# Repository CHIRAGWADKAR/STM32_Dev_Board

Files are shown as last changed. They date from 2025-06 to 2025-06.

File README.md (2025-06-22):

# STM32 PCB Design Project

## STM32F103C8T6 Dev Board (Custom PCB)

This repository contains the complete KiCad project files for a custom development board based on the **STM32F103C8T6** microcontroller, 
commonly used in embedded systems and ARM Cortex-M3 learning platforms.

Designed by: **Chirag Wadkar**  
Toolchain: **KiCad 5.1.15**

---

## 🔧 Features & Specifications

- **Microcontroller**: STM32F103C8T6 (ARM Cortex-M3, 72 MHz, 64 KB Flash, 20 KB RAM)
- **Voltage Regulation**: AMS1117-3.3 LDO with LED power indicator
- **Power Supply**: USB Micro-B (VBus) → 3.3V regulated
- **External Oscillator**:
  - 16 MHz crystal connected to PD0 (HSE_IN) & PD1 (HSE_OUT)
- **USB Interface**:
  - USB Micro-B connected to PA11 (D-) and PA12 (D+)
  - 1.5kΩ pull-up resistor on D+
- **Communication**:
  - UART: PB6 (TX), PB7 (RX)
  - I2C: PB10 (SCL), PB11 (SDA)

---

## 📷 Screenshots

### 🔌 Schematic View
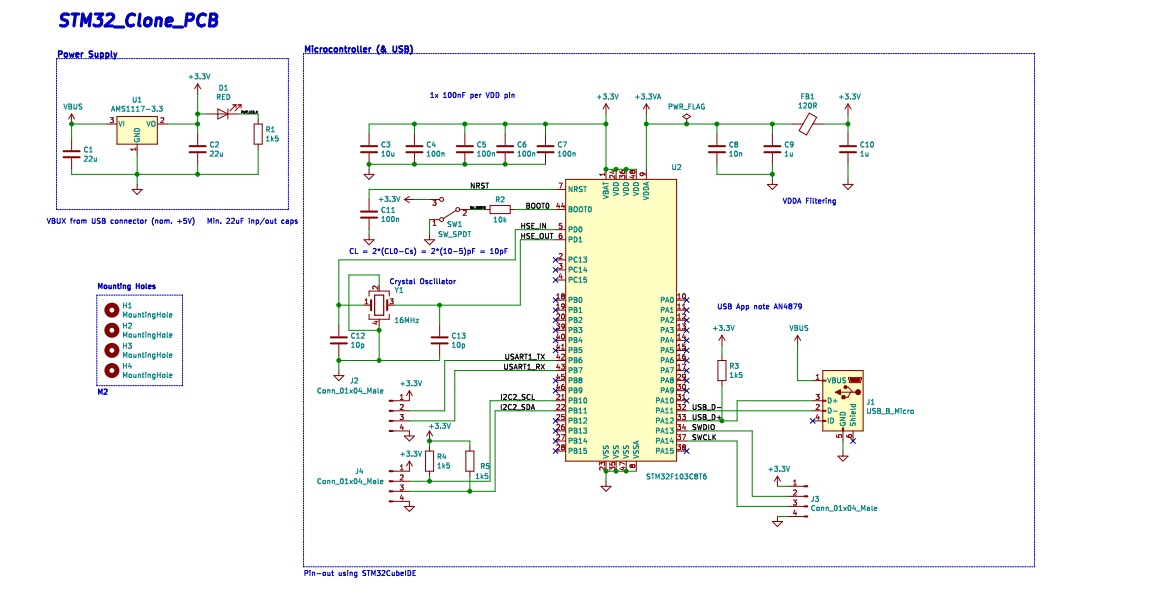
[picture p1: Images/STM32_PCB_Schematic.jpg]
Schematic


### 💻 PCB Layout
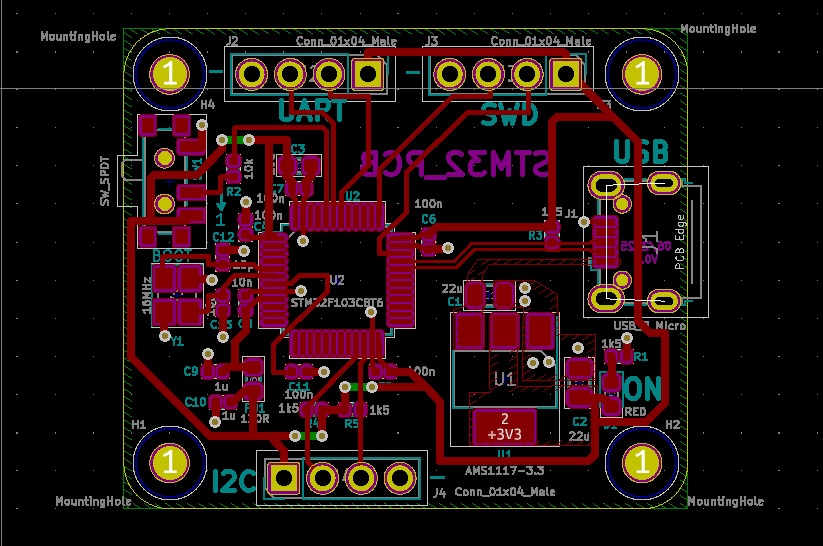
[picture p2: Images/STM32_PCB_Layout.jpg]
PCB Layout


### 🧱 3D Render
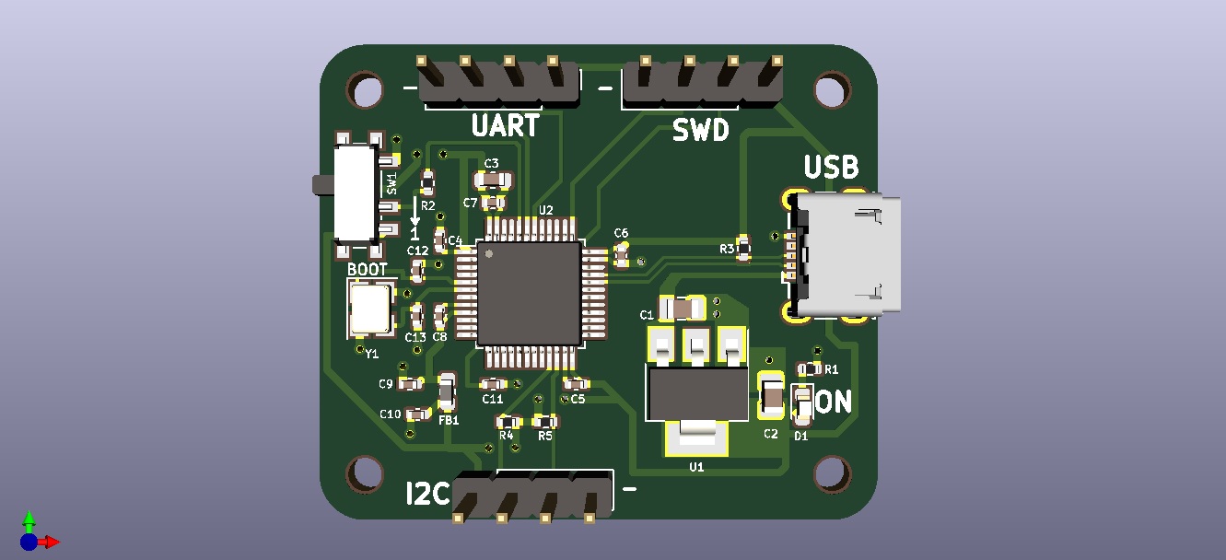
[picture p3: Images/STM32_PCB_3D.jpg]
3D PCB


---

## 🔌 Powering & Programming

- **Power Input**: USB Micro-B (VBus 5V → Regulated to 3.3V)
- **Programming Methods**:
  - Via USB (DFU mode)
  - External SWD programmer via SWDIO/SWCLK pins.

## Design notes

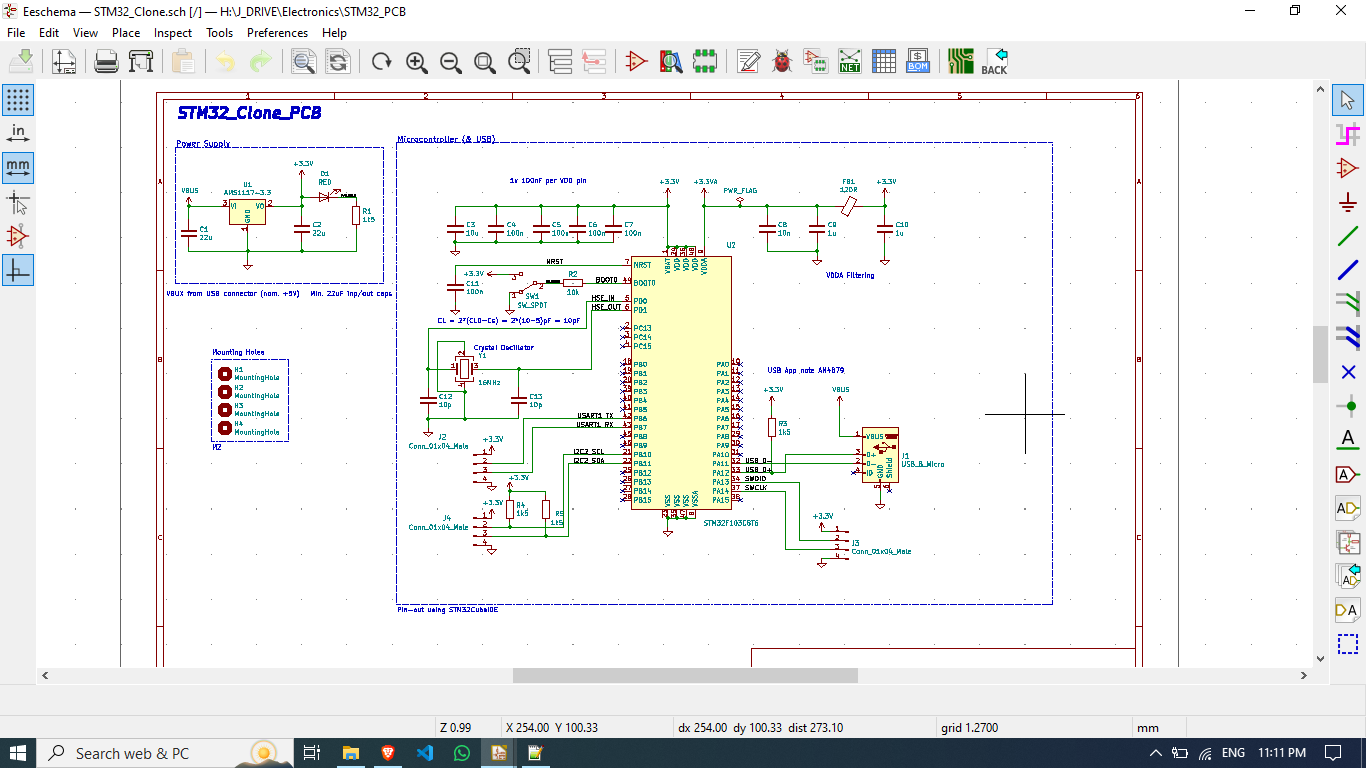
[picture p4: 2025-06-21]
Images/STM32_PCB_Schematic_KiCad.png

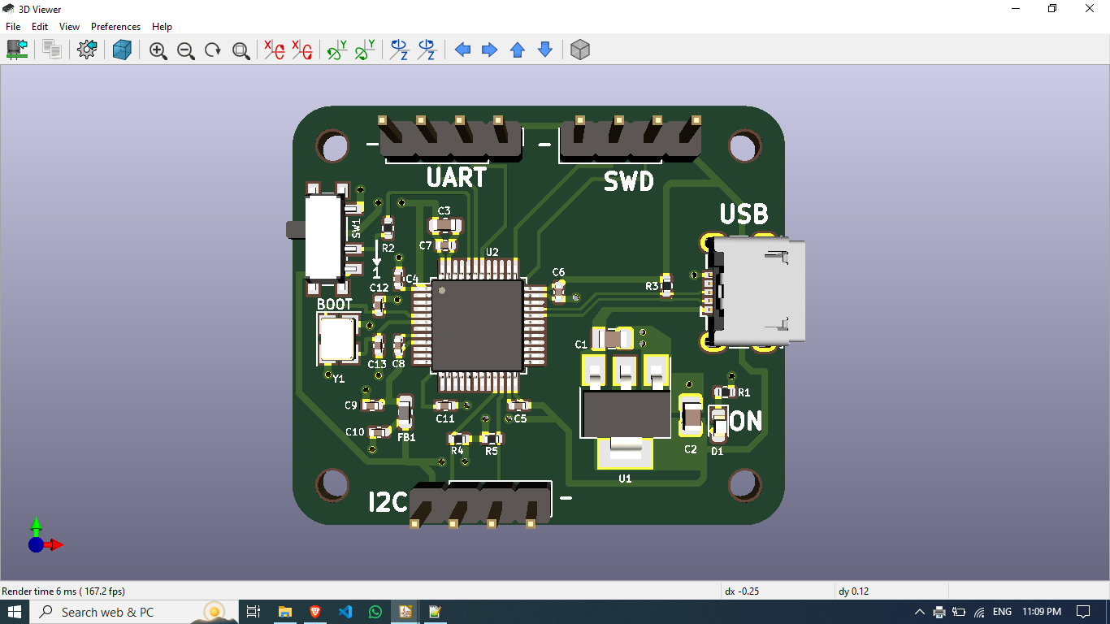
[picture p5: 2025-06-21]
Images/STM32_PCB_3D_KiCad.png

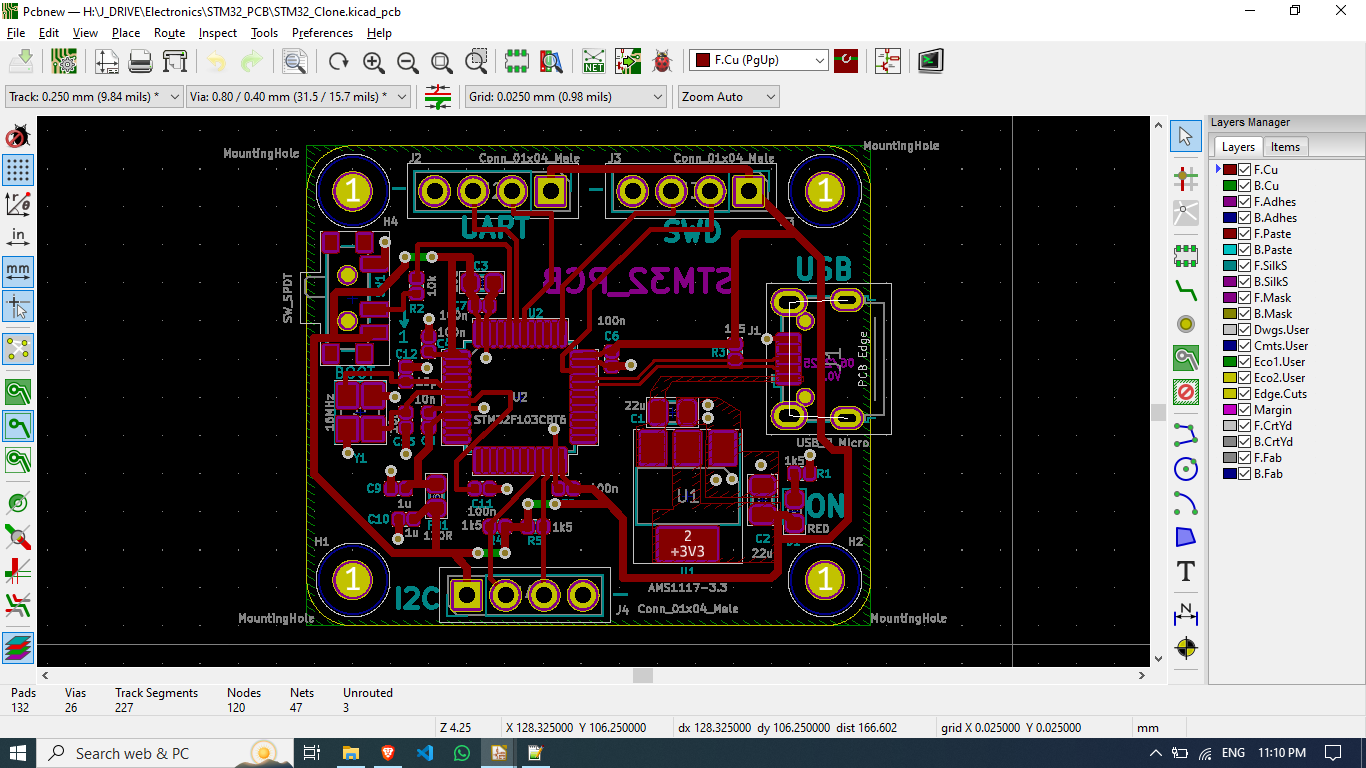
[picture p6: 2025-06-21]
Images/STM32_PCB_Layout_KiCad.png

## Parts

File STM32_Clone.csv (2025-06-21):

Source: | H:\J_DRIVE\Electronics\STM32_Clone\STM32_Clone.sch
Date: | 17-Jun-25 8:03:20 PM
Tool: | Eeschema (5.1.10)-1
Generator: | C:\Program Files\KiCad\bin\scripting\plugins/bom_csv_grouped_by_value_with_fp.py
Component Count: | 32
Ref | Qnty | Value | Cmp name | Footprint | Description | Vendor
C1, C2, | 2 | 22u | C | Capacitor_SMD:C_0805_2012Metric | Unpolarized capacitor
C3, | 1 | 10u | C | Capacitor_SMD:C_0603_1608Metric | Unpolarized capacitor
C4, C5, C6, C7, C11, | 5 | 100n | C | Capacitor_SMD:C_0402_1005Metric | Unpolarized capacitor
C8, | 1 | 10n | C | Capacitor_SMD:C_0402_1005Metric | Unpolarized capacitor
C9, C10, | 2 | 1u | C | Capacitor_SMD:C_0402_1005Metric | Unpolarized capacitor
C12, C13, | 2 | 10p | C | Capacitor_SMD:C_0402_1005Metric | Unpolarized capacitor
D1, | 1 | RED | LED | LED_SMD:LED_0603_1608Metric | Light emitting diode
FB1, | 1 | 120R | Ferrite_Bead | Inductor_SMD:L_0603_1608Metric | Ferrite bead
H1, H2, H3, H4, | 4 | MountingHole | MountingHole | MountingHole:MountingHole_2.2mm_M2 | Mounting Hole without connection
J1, | 1 | USB_B_Micro | USB_B_Micro | Connector_USB:USB_Micro-B_Wuerth_629105150521 | USB Micro Type B connector
J2, J3, J4, | 3 | Conn_01x04_Male | Conn_01x04_Male | Connector_PinHeader_2.54mm:PinHeader_1x04_P2.54mm_Vertical | Generic connector, single row, 01x04, script generated (kicad-library-utils/schlib/autogen/connector/)
R1, R3, R4, R5, | 4 | 1k5 | R | Resistor_SMD:R_0402_1005Metric | Resistor
R2, | 1 | 10k | R | Resistor_SMD:R_0402_1005Metric | Resistor
SW1, | 1 | SW_SPDT | SW_SPDT | Button_Switch_SMD:SW_SPDT_PCM12 | Switch, single pole double throw
U1, | 1 | AMS1117-3.3 | AMS1117-3.3 | Package_TO_SOT_SMD:SOT-223-3_TabPin2 | 1A Low Dropout regulator, positive, 3.3V fixed output, SOT-223
U2, | 1 | STM32F103C8T6 | STM32F103C8Tx | Package_QFP:LQFP-48_7x7mm_P0.5mm | ARM Cortex-M3 MCU, 64KB flash, 20KB RAM, 72MHz, 2-3.6V, 37 GPIO, LQFP-48
Y1, | 1 | 16MHz | Crystal_GND24 | Crystal:Crystal_SMD_3225-4Pin_3.2x2.5mm | Four pin crystal, GND on pins 2 and 4

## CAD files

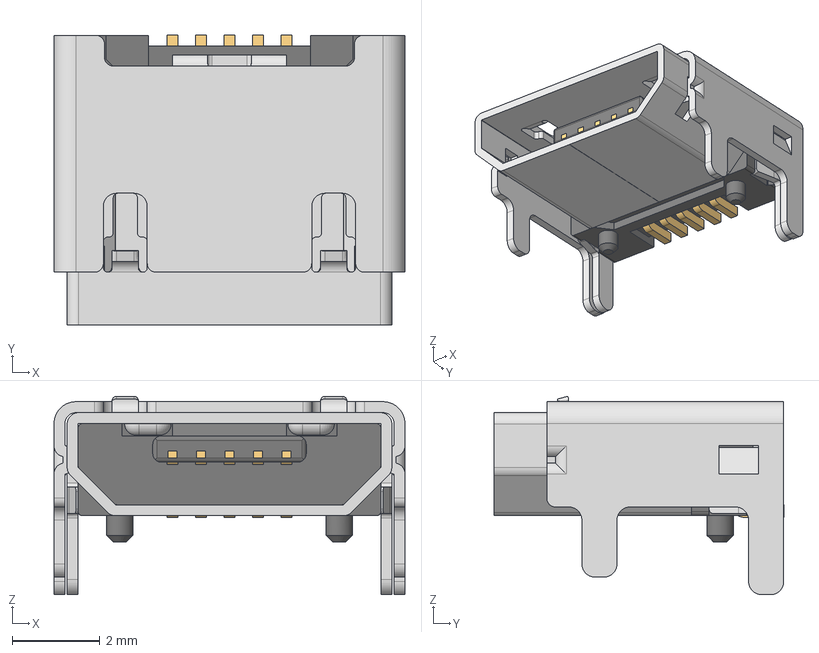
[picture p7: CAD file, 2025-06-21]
629105150521 (rev1).stp
8.00 x 6.60 x 4.52 mm
629105150521_Housing
629105150521_Pin1 x 4
629105150521_Pin2
629105150521_Shielding2
629105150521_Shielding

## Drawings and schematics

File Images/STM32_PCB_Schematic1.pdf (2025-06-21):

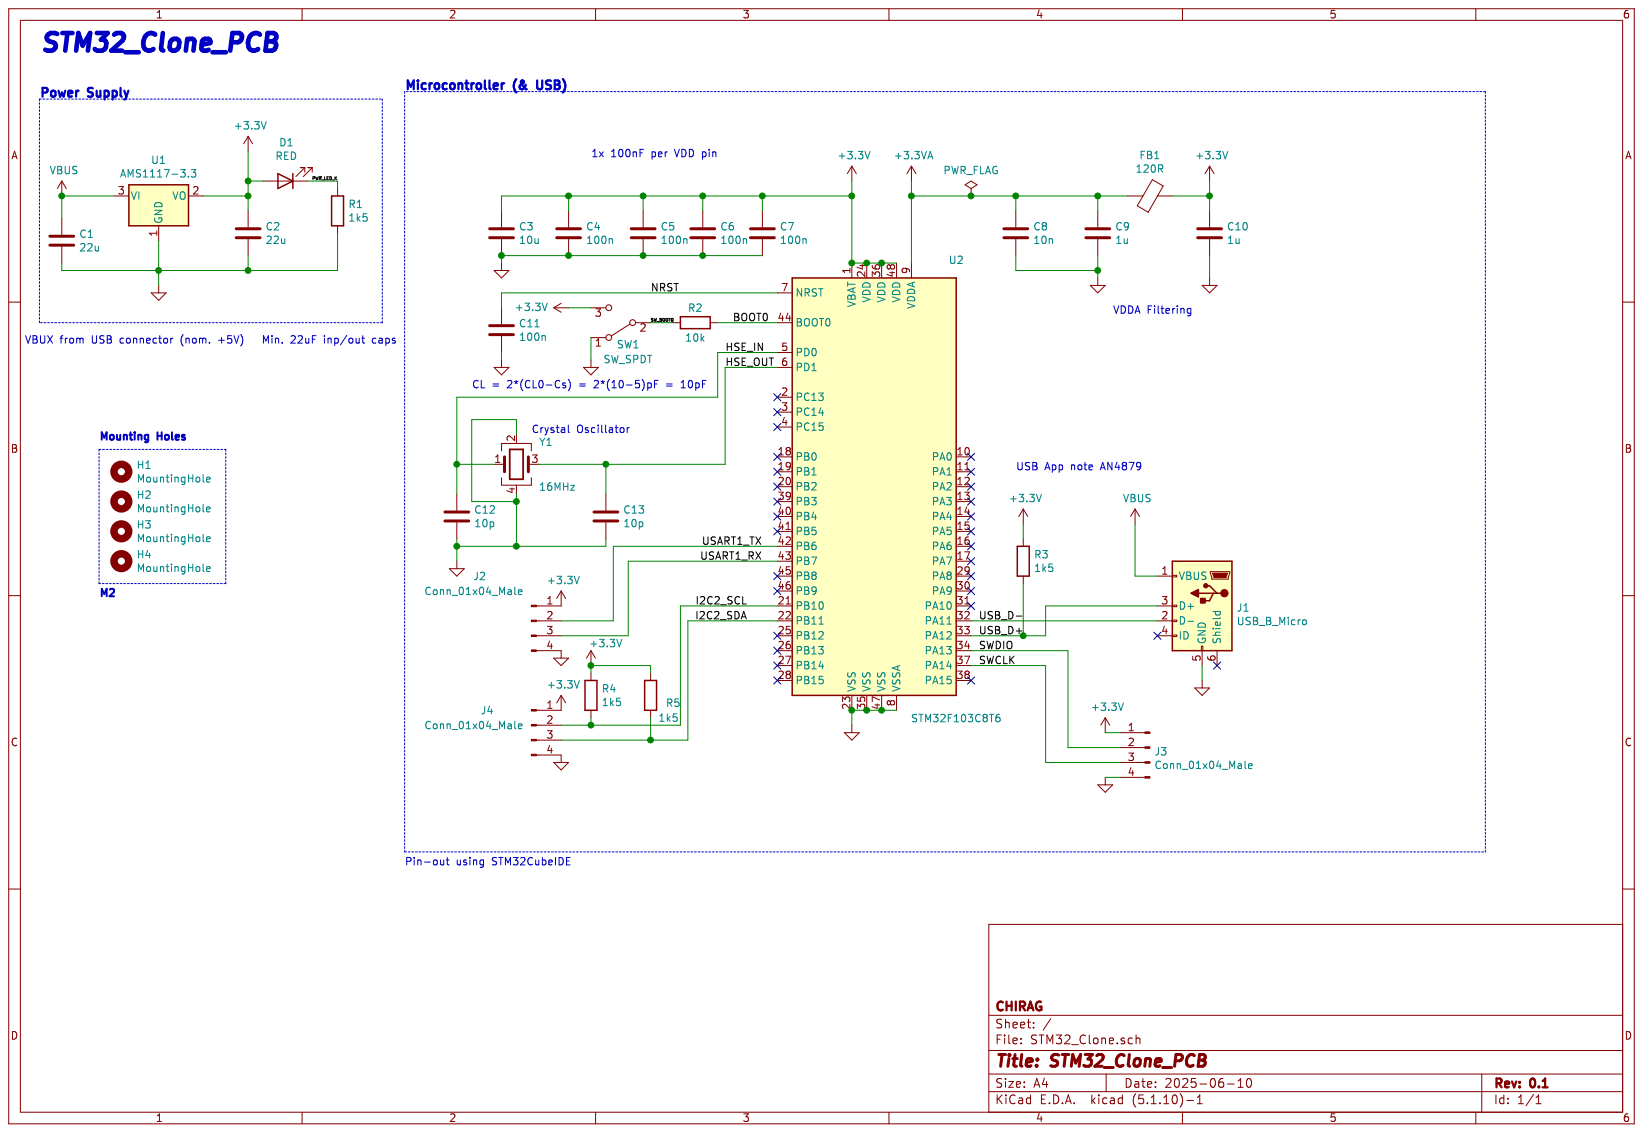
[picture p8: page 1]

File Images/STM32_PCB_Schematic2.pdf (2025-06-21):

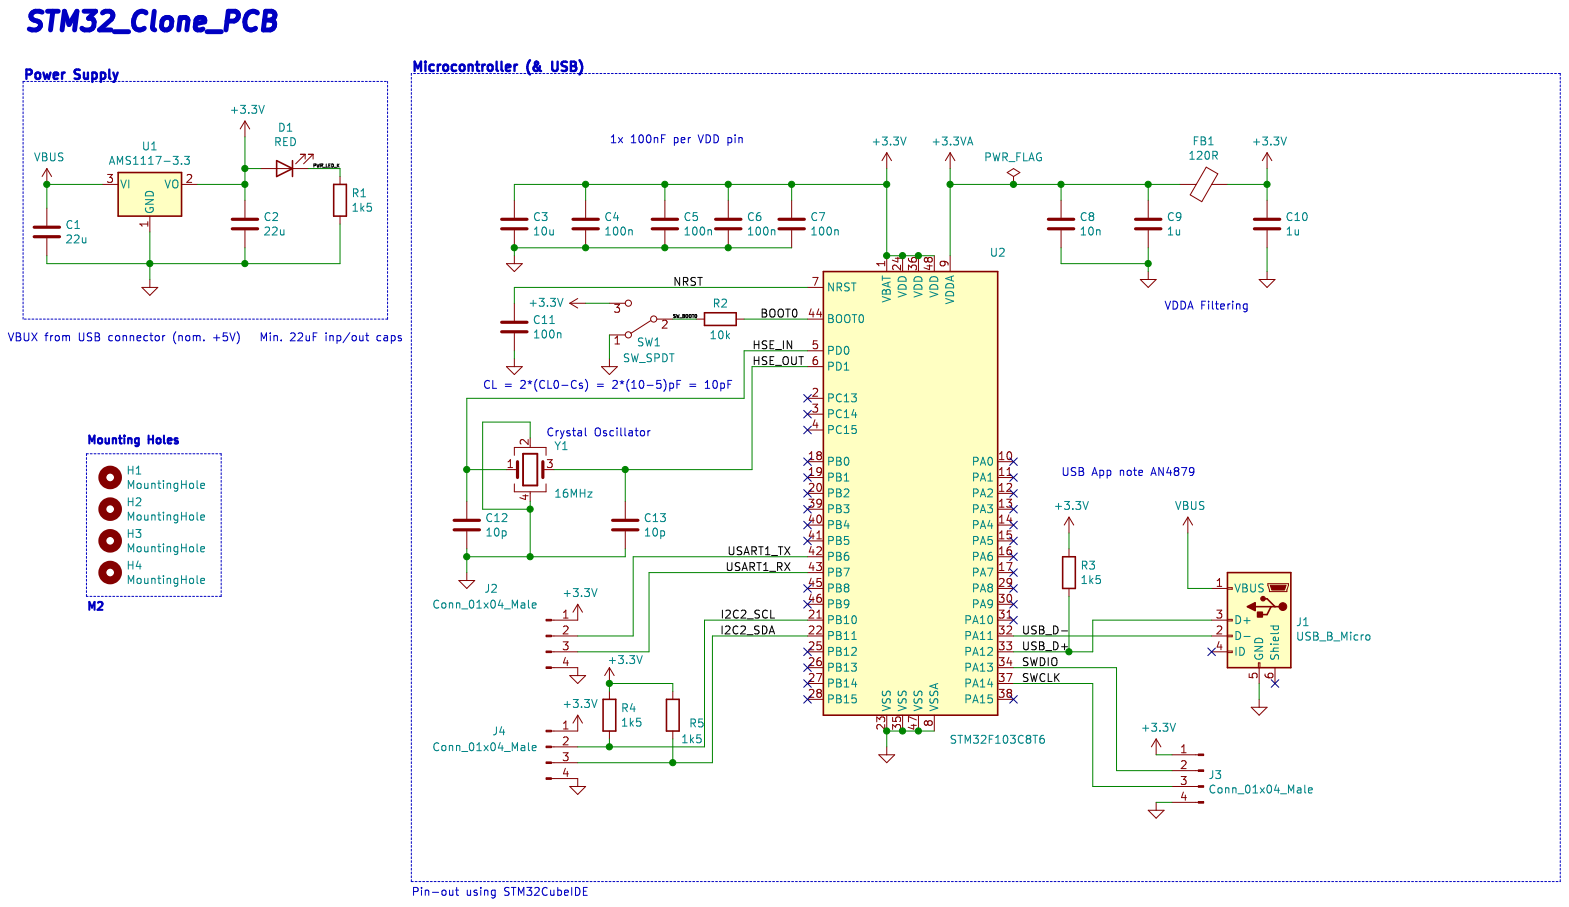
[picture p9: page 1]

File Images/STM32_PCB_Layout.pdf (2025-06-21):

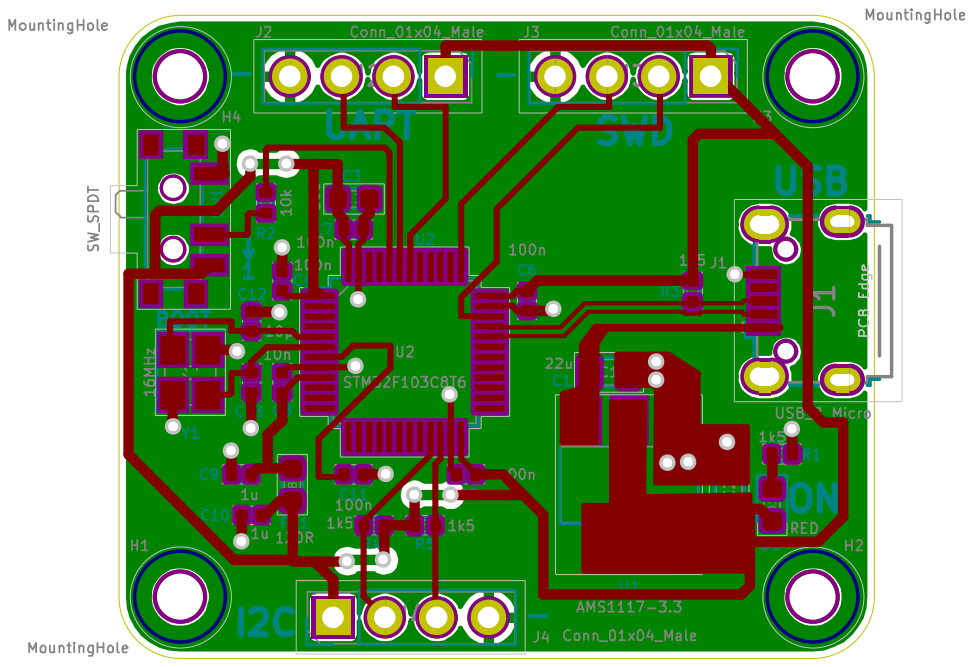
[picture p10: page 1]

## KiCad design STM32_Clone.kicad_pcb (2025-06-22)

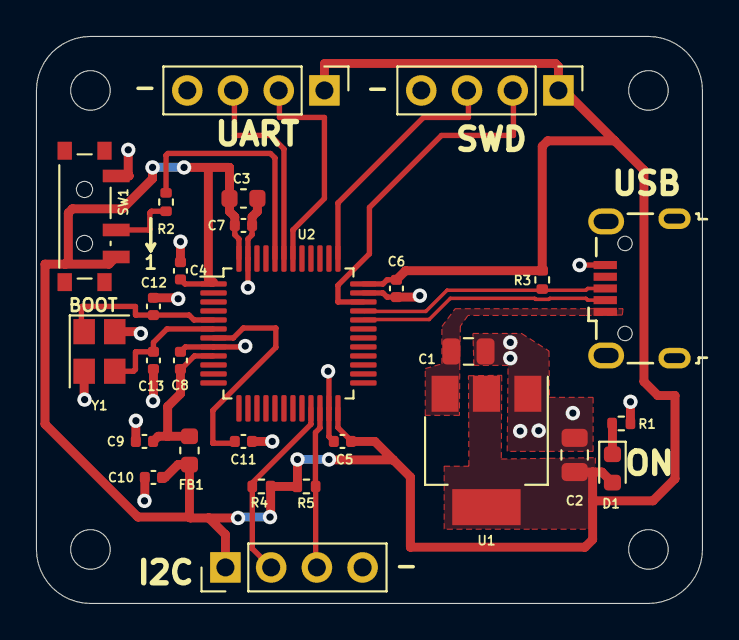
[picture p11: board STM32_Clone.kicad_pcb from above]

Board: 2 copper layers, 37.0 x 31.5 mm, 32 parts (0 on the bottom side), 18 nets.

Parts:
C1, C2: 22u; C_0805_2012Metric
C3: 10u; C_0603_1608Metric
C4, C5, C6, C7, C11: 100n; C_0402_1005Metric
C8: 10n; C_0402_1005Metric
C9, C10: 1u; C_0402_1005Metric
C12, C13: 10p; C_0402_1005Metric
D1: RED; LED_0603_1608Metric
FB1: 120R; L_0603_1608Metric
H1, H2, H3, H4: MountingHole; MountingHole_2.2mm_M2
J1: USB_B_Micro; USB_Micro-B_Wuerth_629105150521
J2, J3, J4: Conn_01x04_Male; PinHeader_1x04_P2.54mm_Vertical
R1, R3, R4, R5: 1k5; R_0402_1005Metric
R2: 10k; R_0402_1005Metric
SW1: SW_SPDT; SW_SPDT_PCM12
U1: AMS1117-3.3; SOT-223-3_TabPin2
U2: STM32F103C8T6; LQFP-48_7x7mm_P0.5mm
Y1: 16MHz; Crystal_SMD_3225-4Pin_3.2x2.5mm

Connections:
+3.3VA: C8.1, C9.1, FB1.2, U2.9
+3V3: C2.1, C3.1, C4.1, C5.1, C6.1, C7.1, C10.1, D1.2, FB1.1, J2.1, J3.1, J4.1, R3.1, R4.1, R5.1, SW1.3, U1.2, U2.1, U2.24, U2.36, U2.48
/BOOT0: R2.1, U2.44
/HSE_IN: C12.1, U2.5, Y1.1
/HSE_OUT: C13.1, U2.6, Y1.3
/I2C2_SCL: J4.2, R4.2, U2.21
/I2C2_SDA: J4.3, R5.2, U2.22
/NRST: C11.1, U2.7
/PWR_LED_K: D1.1, R1.1
/SWCLK: J3.3, U2.37
/SWDIO: J3.2, U2.34
/SW_BOOT0: R2.2, SW1.2
/USART1_RX: J2.3, U2.43
/USART1_TX: J2.2, U2.42
/USB_D+: J1.3, R3.2, U2.33
/USB_D-: J1.2, U2.32
GND: C1.2, C2.2, C3.2, C4.2, C5.2, C6.2, C7.2, C8.2, C9.2, C10.2, C11.2, C12.2, C13.2, J1.5, J2.4, J3.4, J4.4, R1.2, SW1.1, U1.1, U2.8, U2.23, U2.35, U2.47, Y1.2, Y1.4
VBUS: C1.1, J1.1, U1.3

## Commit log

2025-06-21 Initial Commit - STM32 PCB
    [629105150521 (rev1).stp, STM32_Clone.csv, STM32_Clone.kicad_pcb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]
2025-06-21 added gerber files
    [STM32_Clone-B_Cu.gbr, STM32_Clone-B_Mask.gbr, STM32_Clone-B_Paste.gbr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]
